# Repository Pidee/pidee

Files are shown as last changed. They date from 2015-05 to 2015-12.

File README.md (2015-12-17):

github-logo

# The breakout board for the Raspberry Pi with switches, a button and 3 LEDs. #

Current getting started guide is [here](pidee-service/README.md)

## How do you pronounce Pidee? ##

_Pie-dee_

## What can I do with Pidee? ##

Here are some ideas:

- The button
    - Launch and restart applications
    - Soft restarts (push and hold for 3 seconds?)
    - Ping a server when pressed
- The switch
    - Run different applications at startup
    - Boot into the desktop or command line
    - Switch to debug mode
    - Identify multiple Raspberry Pi
    - Have secret pin code to boot the Pi
    - Leave the keyboard and use the switches
- Leds
    - Morse code the IP address at boot?
    - Blink an LED from terminal so you can see which Raspberry Pi you're connected to
    - Show which applications are running
    - Show warnings
    - Show debug mode
    - Disco!
    - Indicate activity

## Why make a Pidee? ##

We wanted to make a cheap-as-possible, robust and readily available human interface for everyone.

Almost anything can be done with the Raspberry Pi GPIO. But again and again, we find ourselves wishing we had to hand a switch, a button or a light to blink. This could save you plugging in a monitor, bringing a keyboard, opening up a terminal or going hunting for the IP address.

You may be creating an installation with hunderds of Raspberry Pis and need to give them all a unique ID. Or you may need to boot a different program when you use your Raspberry Pi in a greenhouse to when you use it in school. Or you might want to enable a debug mode. Or maybe you just want a button to shutdown a Raspberry Pi cleanly? Oh wait... of course you do that anyway!

With this in mind we wanted to make something cheap. We can have it kicking around or buy in multiples. Something robust. We could use it at home, at work and avoid breadboard botched jobs. Something simple. So kids in schools can jump in and program with the GPIO right away. Something safe. Set an input to an output and not fry the Pi. This is why made the Pidee board and we hope you like it too. 

## Who makes a Pidee? ##

Pidee is a collaborative effort instigated by [Stefan Dzisiewski-Smith](http://www.bycgwtsf.com), [The Workers](http://theworkers.net/) and our friends at [The Hackney Swingers Club](http://hackneyswingers.club)

## What's with the extra header pins? ##

More on this soon but did you know that you can access the console without a monitor or a network?

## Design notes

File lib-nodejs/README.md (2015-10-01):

Pidee Node.js Module
====================

Requirements
============

If you have not do so already, `pidee-service` needs to be installed and running on the Raspberry Pi.

### Installing pidee-service

To install and run `pidee-service` first ssh into your Raspberry Pi then run the following commands:

```Bash
sudo echo "deb http://pidee.theworkers.net/raspbian wheezy main" >> /etc/apt/sources.list
wget -qO - http://pidee.theworkers.net/pidee.public.key | sudo apt-key add -
sudo apt-get update
sudo apt-get install pidee
```

How to use
==========

`npm install pidee`

Adds the node pidee module from npm to your project.

API
===

###  pidee.on( domain, callback )
Listen for pidee change events. The domain can be: `'dip'`, `'button'`, `'dip.1'`, `'dip.2'`. See [domains](#domains) for full list.

Example:  
```
pidee.on( 'bottom', function ( value ) {
    // Button has changed
});
```

### pidee.get( domain )
Returns a value on the pidee board. The domain can be: `'dip'`, `'button'`, `'dip.1'`, `'dip.2'` etc. See [domains](#domains) for full list.

Example:  
`var value = pidee.get( 'dip.1' ) // return 0 or 1`

### pidee.set( domain, value )
Sets the value of the leds. The domain can be: `'led.yellow'`, `'led.green'`, `'led.blue'`. See [domains](#domains) for full list.

Example:  
`var value = pidee.get( 'led.yellow', true );

### pidee.on( 'error', callback )
Listen to error events. The callback function should be in the form: `function ( err, errorCode, message )`. Without this errors will be thrown.

Example:
```
pidee.on( 'error', function ( err, errorCode, message ) {
    console.log( 'Pidee error:', err );
    console.log( 'Pidee error code:', code );
    console.log( 'Pidee error message:', message );
});
```

Example
=======

```JavaScript

var Pidee = require( 'pidee' );

var pidee = new Pidee();

pidee.on( 'error', function ( err, code, message ) {
    console.log( 'Pidee error:', err );
    console.log( 'Pidee error code:', code );
    console.log( 'Pidee error message:', message );
});

pidee.open( function () {

    // Turn on yellow led
    pidee.set( 'led.yellow', Pidee.ON );

    // Get the dip value
    var value = pidee.get( 'dip' );

    // Listen for button presses
    pidee.on( 'button', function ( value ) {
        console.log( 'Button changes', value );
    });

});
```

Domains
=======

| Domain | Value Range | 
|---|:---:|
| _all_ | |
| __led__ | [0,7] |
| __led.yellow__  | [0,1] |
| __led.green__ | [0,1] |
| __led.red__ | [0,1] |
| __dip__ | [0,255] |
| __dip.0__ | [0,1] |
| __dip.1__ | [0,1] |
| __dip.2__ | [0,1] |
| __dip.3__ | [0,1] |
| __dip.4__ | [0,1] |
| __dip.5__ | [0,1] |
| __dip.6__ | [0,1] |
| __dip.7__ | [0,1] |
| __button__ | [0,1] |

| Domain  | GET | SET | ON |
|---|:---:|:---:|:---:|
| led | | &#x2713; | | 
| dip | &#x2713; | | &#x2713; | 
| button  | &#x2713; | | &#x2713; | 
| _all_ | &#x2713; | | &#x2713; |

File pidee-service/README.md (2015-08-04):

# Pidee Service

- [Getting Started with Pidee Service](#getting-started-with-pidee-service)
    - [Examples](#examples)
- [Developers](#developers-how-to-communicate-with-pidee-service-)
- [Using Pidee Board without Pidee Service](#using-pidee-board-without-pidee-service)

## Getting started with Pidee Service

You can likely skip step one if pidee has been install via the package manager.

1. Run **pidee-service** with `sudo bin/pidee-service`
2. In another terminal session, try running **pidee-cli** by `cd`ing into your Pidee folder, then the `pidee-service` folder and then run `bin/pidee-cli` 

## Examples

Run the following examples from the `pidee/bin` folder (with `cd bin`)

##### Turn on the yellow LED

`./pidee-cli set led.yellow 1`

##### Turn off the yellow LED

`./pidee-cli set led.yellow 0`

#### Get the value of the dip switches

`./pidee-cli get dip`

_Voilà! You have id'ed the pi the with a Pidee!_

#### Get the value of the third dip switch

`./pidee-cli get dip.2`

#### See if the button is pressed

`./pidee-cli get button`

#### Get all switches and button values

`./pidee-cli get all`

#### Set all the LEDs to off

`./pidee-cli set led 0`

#### Set all the LEDs on

`./pidee-cli set led 0`

_Intrigued? You can set the three LEDs at once using a binary bitmask_

#### Listen for the button to be pressed or lifted

`./pidee-cli subscribe button`

*Push `Ctrl-C` to quit it*

#### Listen for the dip switch to change

`./pidee-cli subscribe dip`

#### Listen for the 6th dip switch to change

`./pidee-cli subscribe dip.6`

#### Listen any changes to the dip or the switch

`./pidee-cli subscribe all`

## Developers (How to communicate with pidee-service )

In the examples above `pidee-cli` sends commands to the pidee service via a unix socket files. Check the [Protocol Document](Protocol.md) for more info on how the commands are structures. If you want to test the protocol you can do so in the terminal. Here is an example:

```
echo "#foo led.yellow SET 1" | nc -U /tmp/pidee.sock
```

The command, which is defined in the protocol documents, is `#foo led.yellow SET 1`. `nc` is a utility to write to the socket. Most programming languages will give you a way to do this.

# Using Pidee Board without Pidee Service 

Of course, you can ditch pidee-service all together and just use the GPIO on the rasppbery pi directly. Checkout the schmantic for the board [here](../pcb/export/drawings/Pidee%20Schematic.pdf) and [wiring-pi](http://wiring-pi.com/) to interface with the GPIO.

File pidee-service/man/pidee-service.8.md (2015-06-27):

PIDEE SERVICE 8
===============

NAME
----

pidee-service - System deamon for the Pidee Raspberry Pi add-on board.

SYNOPSIS
--------

`pidee` [`options`] [`command`]

DESCRIPTION
-----------

`pidee` 

OPTIONS
-------

`-h, --help`
  Output usage information

`-V, --version`
  Output version information

COMMANDS
--------

`set` [`color`] [`value`]
  set LED (red|yellow|green) to between 0 - 1

`dip`
  reads all DIP switch values as an integer value

`switch` [`switch-number`]
  reads a switch value as either 0 or 1

FILES
-----

*/etc/pidee.conf*
  The system wide configuration file.  

*~/.pideerc*
  Per user configuration file. See pidee-service(8) for further details.

ENVIRONMENT
-----------

`PIDEE_SOMETHING`
  If non-null the full pathname for an alternate system wide */etc/foo.conf*.  
  Overridden by the `-c` option.

DIAGNOSTICS
-----------

The following diagnostics may be issued on stderr:

**Some heading**
  `pidee` can only handle pies.

BUGS
----

None known.

AUTHOR
------

The Workers <pidee@theworkers.net>

SEE ALSO
--------

pidee(1), [Pidee website](http://pidee.org)

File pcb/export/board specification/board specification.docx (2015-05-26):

# PCB specification for Pidee v1.0

PCB substrate | FR4
PCB thickness | 1.6mm
Number of layers | 2
Copper weight | 1oz / sq. ft (35 um)
Number of resist layers | 2
Resist colour | Matt black
Number of ident layers | 0
Ident colour | n/a
Copper finish | ENIG
Panelisation requirements | To be panelised 30-up as per panelisation drawing. Panelised Gerbers to be approved before production begins. If in doubt please ask. parts.

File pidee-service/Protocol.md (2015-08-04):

Protocol
========

Overview
--------

`<REQ-TOKEN> <DOMAIN> <METHOD> [<VALUE>]`

## Requests

- `<REQ-TOKEN> <DOMAIN> GET`
- `<REQ-TOKEN> <DOMAIN> SET <VALUE>`
- `<REQ-TOKEN> <DOMAIN> SUBSCRIBE`
- `<REQ-TOKEN> <DOMAIN> UNSUBSCRIBE`

_Note: `<REQ-TOKEN>` is a word starting with #

## Response

- `ERROR <CODE> <MESSAGE>` _Error, for request without token_
- `<REQ-TOKEN> ERROR <CODE> <MESSAGE>` _Error, for request with token_
- `<REQ-TOKEN> <DOMAIN> <VALUE>` _Subscription responces_
- `<REQ-TOKEN> DONE` _All responses sent_

Domains
-------

| Domain | Value Range | 
|---|:---:|
| _all_ | |
| __led__ | [0,7] |
| __led.yellow__  | [0,1] |
| __led.green__ | [0,1] |
| __led.red__ | [0,1] |
| __dip__ | [0,255] |
| __dip.0__ | [0,1] |
| __dip.1__ | [0,1] |
| __dip.2__ | [0,1] |
| __dip.3__ | [0,1] |
| __dip.4__ | [0,1] |
| __dip.5__ | [0,1] |
| __dip.6__ | [0,1] |
| __dip.7__ | [0,1] |
| __button__ | [0,1] |

| Domain  | GET | SET | (UN)SUBSCRIBE |
|---|:---:|:---:|:---:|
| led | | &#x2713; | | 
| dip | &#x2713; | | &#x2713; | 
| button  | &#x2713; | | &#x2713; | 
| _all_ | &#x2713; | | &#x2713; | 

Examples
--------

- `#e324d led.yellow SET 0`

Error Codes
-----------

- 0: Unkown error
- 1: Invaild or missing token
- 2: Invalid or missing domain
- 3: Invalid or missing method
- 4: Missing value
- 5: GET not allowed on domain
- 6: SET not allowed on domain
- 7: SUBSCRIBE and UNSUBSCRIBE not allowed on domain
- 8: Invalid value
- 9: Subscription for token not found

Testing Protocol in Terminal
----------------------------

```bash
echo "#12341234 led SET 5" | nc -U /tmp/pidee.sock
```

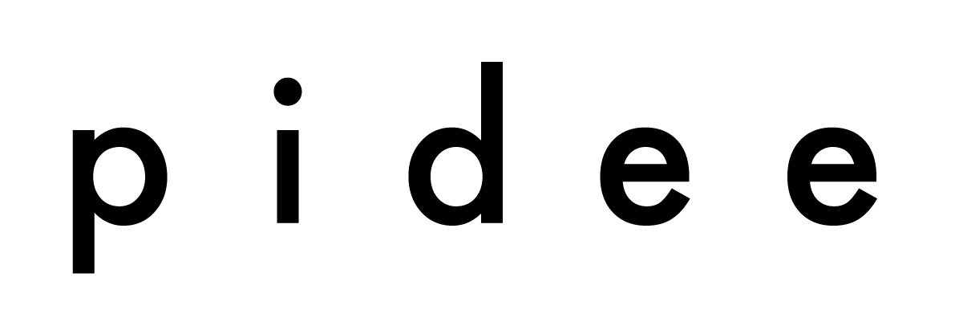
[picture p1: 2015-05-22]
assets/pidee-lowercase.png

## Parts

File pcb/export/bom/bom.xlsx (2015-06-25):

RefDes | Value | Name | Pattern | Quantity | Wurth |  | Toby |  | 4UCon |  | Bourns |  | TE Connectivity |  | KaiFeng Electronics |  | Line total
CN1 |  | 1x6 | 1x6 male SMD 2 | 1 |  |  |  |  | 11106 | £0.13 |  |  |  |  |  |  | £0.13
D1 | GREEN | LED | DIO_0603 | 1 | 150060VS75000 | £0.03 |  |  |  |  |  |  |  |  |  |  | £0.03
D2 | RED | LED | DIO_0603 | 1 | 150060RS75000 | £0.03 |  |  |  |  |  |  |  |  |  |  | £0.03
D3 | YELLOW | LED | DIO_0603 | 1 | 150060YS75000 | £0.03 |  |  |  |  |  |  |  |  |  |  | £0.03
J1 |  | 90131-0140 | HDR-2x20T/2.54x2.54/51x5 | 1 | 613 040 218 21 | £0.33 |  |  | 00587 | £0.17 |  |  |  |  |  |  | £0.17
R1, R2, R3, R4, R5 | 1k | 741C083 | CAY16-F4/J4 (1206) | 5 |  |  |  |  |  |  | CAY16-102J4LF | £0.01 |  |  |  |  | £0.07
S1 |  | B3FS-1000 | B3FS | 1 | 430 182 043 816 | £0.06 |  |  |  |  |  |  | FSM4JSMA | £0.09 |  |  | £0.06
S2 |  | BD08 | BPA-08S | 1 | 418 121 270 808 | £0.85 | VDIP-1027-8P-B | £0.35 |  |  |  |  |  |  | KF-08P |  | £0.35
 |  | PCB |  | 1 |  |  |  |  |  |  |  |  |  |  |  |  | £0.50
 |  | Assembly |  | 1 |  |  |  |  |  |  |  |  |  |  |  |  | £0.50
 |  |  |  |  |  |  |  |  |  |  |  |  |  | Sub total |  | Sub total | £1.87

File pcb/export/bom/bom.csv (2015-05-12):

RefDes | Value | Name | Pattern | Quantity | Wurth |  | Toby |  | 4UCon |  | Bourns |  | TE Connectivity |  | Line total
CN1 |  | 1x6 | 1x6 male SMD 2 | 1 |  |  |  |  | 11106 | £0.13 |  |  |  |  | £0.13
D1 | YELLOW | LED | DIO_0603 | 1 | 150060YS75000 | £0.01 |  |  |  |  |  |  |  |  | £0.01
D2 | RED | LED | DIO_0603 | 1 | 150060RS75000 | £0.01 |  |  |  |  |  |  |  |  | £0.01
D3 | GREEN | LED | DIO_0603 | 1 | 150060VS75000 | £0.01 |  |  |  |  |  |  |  |  | £0.01
J1 |  | 90131-0140 | HDR-2x20T/2.54x2.54/51x5 | 1 | 613 040 218 21 | £0.33 |  |  | 00587 | £0.17 |  |  |  |  | £0.17
R1, R2, R3, R4, R5 | 1k | 741C083 | CAY16-F4/J4 (1206) | 5 |  |  |  |  |  |  | CAY16-102J4LF | £0.01 |  |  | £0.07
S1 |  | B3FS-1000 | B3FS | 1 | 430 182 043 816 | £0.06 |  |  |  |  |  |  | FSM4JSMA | £0.09 | £0.06
S2 |  | BD08 | BPA-08S | 1 |  |  | VDIP-1027-8P-B | £0.35 |  |  |  |  |  |  | £0.35
 |  |  |  |  |  |  |  |  |  |  |  |  |  | Sub total | £0.81

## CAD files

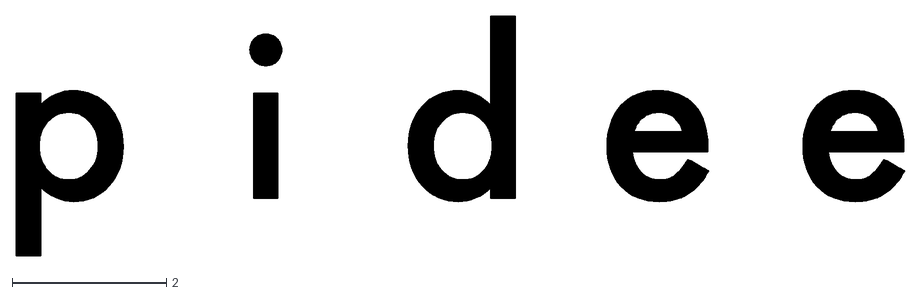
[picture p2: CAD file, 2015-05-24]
assets/pidee-lowercase-split.dxf
11.5 x 3.10

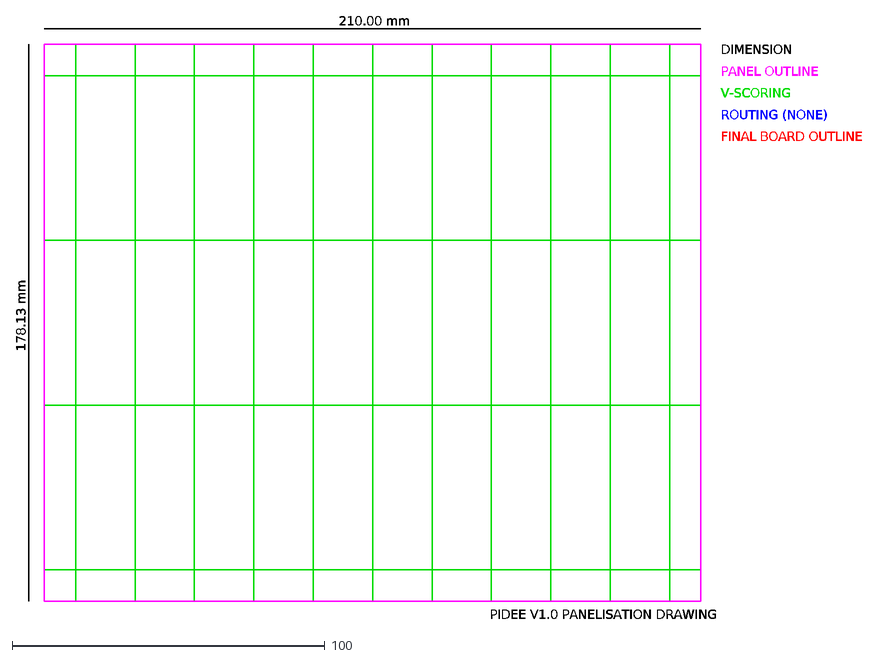
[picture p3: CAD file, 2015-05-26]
pcb/Pidee CAM export v1.0/drawings/Pidee panelisation.dxf
FINAL BOARD OUTLINE
ROUTING (NONE)
V-SCORING
PANEL OUTLINE
210.00 mm
PIDEE V1.0 PANELISATION DRAWING
178.13 mm
DIMENSION

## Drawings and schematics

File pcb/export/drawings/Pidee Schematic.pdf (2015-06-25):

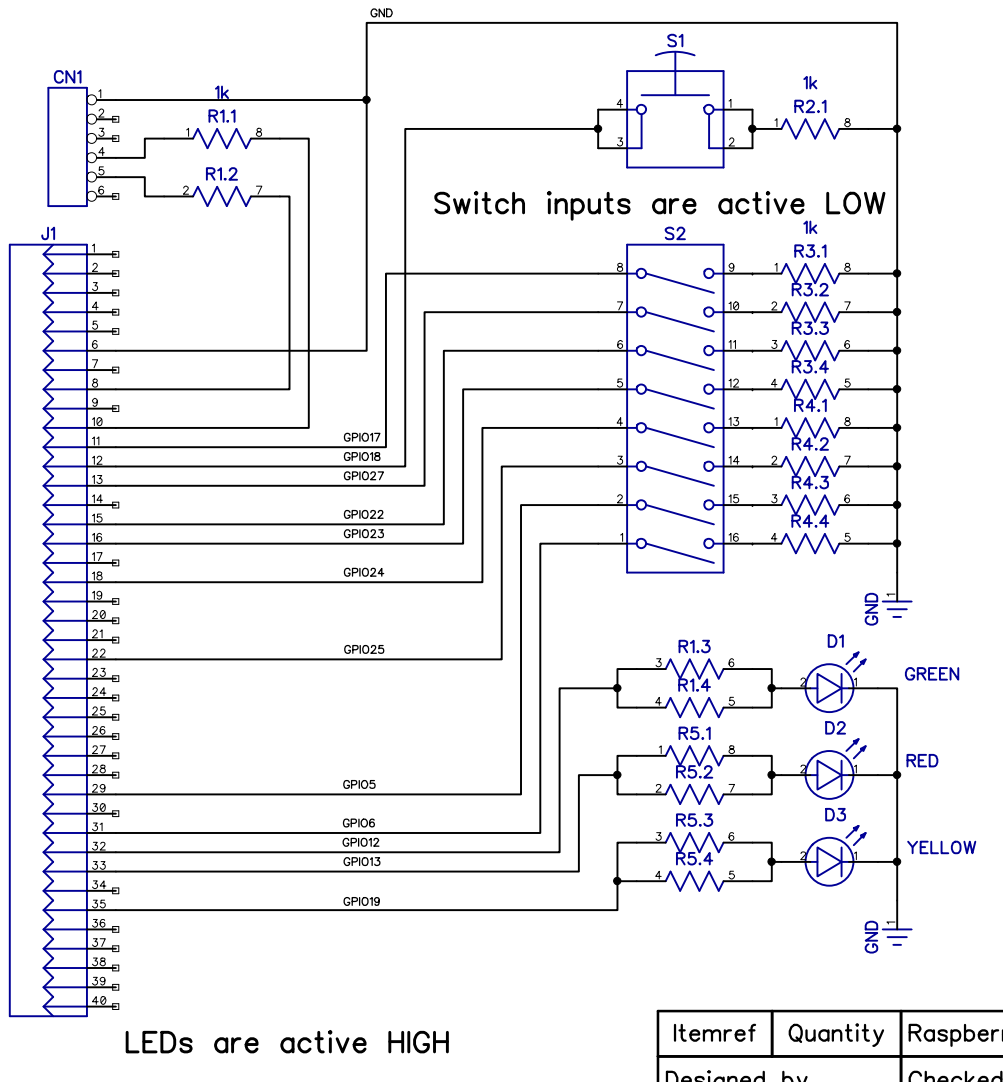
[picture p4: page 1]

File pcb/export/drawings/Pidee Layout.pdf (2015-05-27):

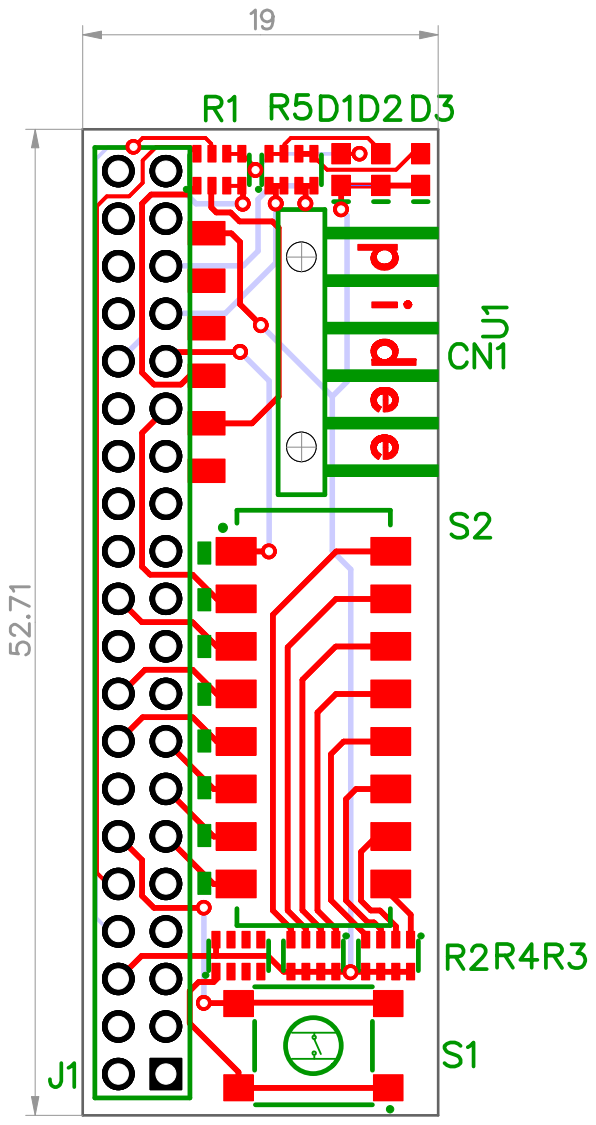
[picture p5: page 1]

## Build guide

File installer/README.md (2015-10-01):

# Pidee Service Package

This is the Raspian / Debian package for the Pidee board system driver and API provider service.

## Installation

There are various ways to install the Pidee service. If you are unsure, use the first option below.

### Option 1: via apt-get

To get started, edit the file  in `/etc/apt/sources.list` and paste or type the following:

If necessary, replace `wheezy` with the name of your Raspbian distribution.

```plain
deb http://pidee.theworkers.net/raspbian wheezy main
```

If you don't know how, you can simply copy-paste the following in the terminal:

```shell
sudo echo "deb http://pidee.theworkers.net/raspbian wheezy main" >> /etc/apt/sources.list
```

Then add Pidee's GPG key, so you can have some confidence that the packages come from the correct server. Again, copy-paste the following in the terminal:

```shell
wget -qO - http://pidee.theworkers.net/pidee.public.key | sudo apt-key add -
```

The above downloads (with `wget`) our public key ([just a text file](http://pidee.theworkers.net/pidee.public.key)) and calls the Debian/Raspbian command `apt-key add` (with `sudo` and getting the key from the result of `wget`)

Once you are done with the steps above, run:

```shell
sudo apt-get update
sudo apt-get install pidee
```

Wait a little and enjoy!

### Option 2: by manually downloading and installing the package with dpkg

Go to [http://pidee.theworkers.net/raspbian/pool/main/p/pidee/](http://pidee.theworkers.net/raspbian/pool/main/p/pidee/) and download the latest version you can find in the list. You can also copy the link and download directly on the Pi via `wget`. See example below.

<!--
from https://raspberry-hosting.com/en/faq/where-can-i-find-actual-haproxy-and-keepalived-deb-packages-raspberry-pi-and-how-i-install-high
-->

```shell
$ wget http://pidee.theworkers.net/raspbian/pool/main/p/pidee/pidee_VERSION_armhf.deb
$ sudo dpkg -i ./pidee_VERSION_armhf.deb
```

Replace `pidee_VERSION_armhf` with an actual version number. For example `pidee_1.0.0_armhf` or whatever is the latest.

## Updating pidee

```shell
sudo apt-get install --only-upgrade pidee
```

## Installation directories

For the curious, the software will be installed into the directory tree below.

- `/etc/pidee` is for the user-editable config file(s?) 
- `/usr/bin` and `/usr/sbin` contain the `pidee` and `pidee-service` executables respectively. These are just bootstrapping the actual code in `/usr/lib/pidee/…`, but it's a standard `PATH` so… we put them here.
- `/usr/lib` is for the actual code (js, modules, node, etc.) We are not using `/usr/local/lib`, [because](https://www.debian.org/doc/manuals/maint-guide/modify.en.html):
    > Most third-party software installs itself in the /usr/local directory hierarchy. On Debian this is reserved for private use by the system administrator, so packages must not use directories such as /usr/local/bin but should instead use system directories such as /usr/bin, obeying the Filesystem Hierarchy Standard (FHS).
- `/var/lib/pidee` is where we should create our `pidee.sock` socket file.
- Log files should end up in `/var/logs/pidee/pidee-service.log`, etc.

```txt
/
├── etc/
│   └── pidee/
│       └── pidee.conf
├── usr/
│   ├── bin/
│   │   └── pidee*
│   ├── lib/
│   │   └── pidee/
│   │       ├── node/
│   │       │   ├── bin/
│   │       │   ├── include/
│   │       │   ├── lib/
│   │       │   └── share/
│   │       ├── pidee/
│   │       │   ├── README.md
│   │       │   ├── bin/
│   │       │   ├── libs/
│   │       │   ├── man/
│   │       │   ├── node_modules/
│   │       │   └── package.json
│   │       ├── pidee.init*
│   │       └── pidee.service
│   ├── sbin/
│   │   └── pidee-service*
│   └── share/
│       ├── doc/
│       │   └── pidee/
│       │       └── README.md
│       └── man/
│           ├── man1/
│           │   └── pidee.1
│           └── man8/
│               └── pidee-service.8
└── var/
    └── lib/
        └── pidee/
```

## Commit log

2015-05-06 Added back toggle led
2015-05-06 Added comments to extra pwm config
2015-05-06 Added back buttons
2015-05-12 Added PCB files - coming in at Rev. 4
    [Board.gbr, BoardOutline.gbr, Bottom.gbr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]
2015-05-12 Minor shunt of accidentally moved resistor array
2015-05-14 Updated panelisation drawing, marked .ai files in the PCB folder as not text
2015-05-14 Oops, incorrect suntax in .gitattributes before. Also, exported DXF of panelisation.
    [Pidee panelisation.dxf]
2015-05-14 Tidied some typos
    Cleaned up some lower case Raspberry Pi instances etc
2015-05-24 Updated BOM + .gitignore to ignore temporary DipTrace files
    [bom.xlsx]
2015-05-24 Up-issued schematic to rev. 5 and updated PCB - now all used pins are towards one end.
2015-05-24 Updated board copper graphics, re-exported Gerber files and drills. Should be ready to send for production, pending
    [Bottom.gbr, BottomAssy.gbr, BottomDimension.gbr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]
2015-05-24 Updated and moved gitattributes to avoid Gerber and Illustrator files being tracked like code
2015-05-24 Updated exported schematic and layout drawings
2015-05-26 Added board spec, upissued to v1.0, updated drawings, approved all components
    [Pidee panelisation.dxf]
2015-05-26 Export for CAM
    [Pidee panelisation.dxf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]
2015-05-27 Moved in track down LHS of board at the board house's request
    [Bottom.gbr, Through.drl, Top.gbr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]
2015-05-31 Small colour map change in PCB source file
2015-06-25 Added new potential switch to BOM
    [bom.xlsx]
2015-06-25 Added quick test functions, updated BOM, PCB CAD and drawings to reflect correct LED order. Did not update from v1.0 as this was a documentation error, not a design change.
    [bom.xlsx]
2015-06-27 Package .deb and tar.gz creation
    Still missing init.d script and a couple of post-install scripts.
    Need to sort out how to point nodejs to the required modules.
    Needs to symlink pidee and pidee-service from lib/pidee (they get copied at the mo)
2015-06-28 Installer and init seem to work. Needs improving. See commit msg
    The init script can start the service, however due to it being interpreted by node in the shebang, the PID is not correct when looking for a process names "pidee-service". Need to find a way to tidy up the PID thing.
    See https://gist.github.com/peterhost/715255 for more
2015-06-30 Needs wiringpi in repo; only compiles on arm
    Need a strategy for *remebering* to update this in the repo.
    ```shell
    pushd /usr/lib/pidee/pidee/node_modules/wiring-pi
    sudo tar cf ~/wiring-pi.tar .
    popd
    ```
2015-06-30 Add precompiled wiringpi node module
2015-07-01 Create /var/lib/pidee
    for the socket file
2015-07-21 Added LED toggle state (high or low)
2015-07-21 Fixed removing of node_modules/wiringpi
2015-07-22 Fixed W.js partial. Working SET led
2015-07-23 Moved pidee-service from prototype
2015-07-23 Removed legacy prototypes
2015-08-04 Fix max led value in range
2015-08-04 Fixed led range
2015-08-04 Updated wiring-pi
2015-08-04 Fixed led order. Closes #47
2015-09-30 Added Scratch (to control leds)
